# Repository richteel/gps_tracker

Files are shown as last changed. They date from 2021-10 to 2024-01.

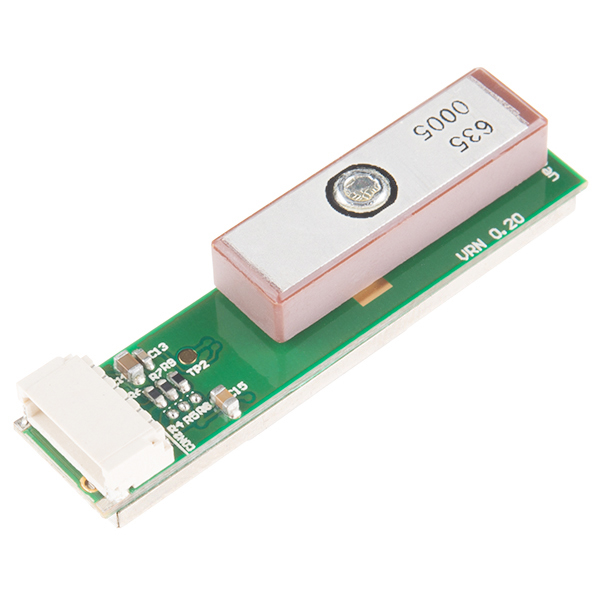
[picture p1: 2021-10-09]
docs/img/13670-01a.jpg

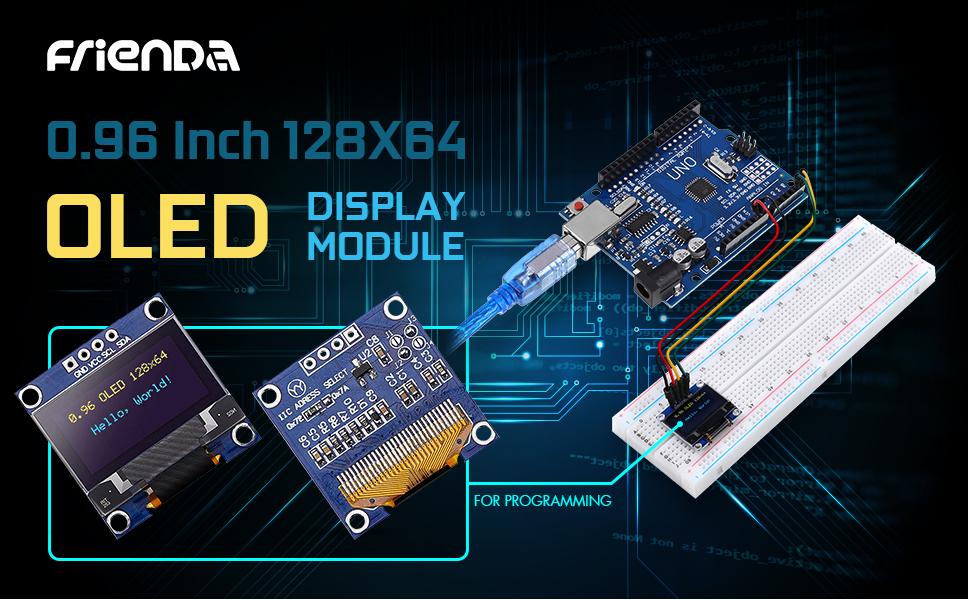
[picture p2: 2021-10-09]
docs/img/444afe57-f2d5-45a5-a1f3-c204e6212a6a.__CR0,0,970,600_PT0_SX970_V1___.jpg

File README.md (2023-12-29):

# gps_tracker
GPS Tracker and data logger

The files here include hardware, case, PCB, Python and C++ code, documentation, and reference files.

## Bill of Materials (BOM) ##
- Adafruit Feather RP2040
	- Qty: 1
	- Source: Adafruit [https://www.adafruit.com/product/4884](https://www.adafruit.com/product/4884 "Adafruit Feather RP2040")
- Adafruit Micro SD Breakout
	- Qty: 1
	- Source: Adafruit [https://www.adafruit.com/product/4682](https://www.adafruit.com/product/4682 "Adafruit Micro SD SPI or SDIO Card Breakout Board - 3V ONLY!")
- SPDT Slide Switch
	- Qty: 2
	- Source: Adafruit [https://www.adafruit.com/product/805](https://www.adafruit.com/product/805 "SPDT Slide Switch")
- Tactile Switch Push Button (6mm slim)
	- Qty: 4
	- Source: Adafruit [https://www.adafruit.com/product/1489](https://www.adafruit.com/product/1489 "Tactile Switch Push Button (6mm slim)")
- ST-PH 2-Pin SMT Right Angle Connector
	- Qty: 1
	- Source: Adafruit [https://www.adafruit.com/product/1769](https://www.adafruit.com/product/1769 "ST-PH 2-Pin SMT Right Angle Connector")
- GPS Receiver - GP-635T (50 Channel)
	- Qty: 1
	- Source: Sparkfun [https://www.sparkfun.com/products/retired/11571](https://www.sparkfun.com/products/retired/11571 "GPS Receiver - GP-635T (50 Channel)")
- JST SH Jumper 6 Wire Assembly - 8"
	- Qty: 1
	- Source: Sparkfun [https://www.sparkfun.com/products/10361](https://www.sparkfun.com/products/10361 "JST SH Jumper 6 Wire Assembly - 8 inch")
- I2C 128x64 OLED Display
	- Qty: 1
	- Source: Amazon [https://www.amazon.com/gp/product/B08VNRH5HR/ref=ppx_yo_dt_b_search_asin_title?ie=UTF8&th=1](https://www.amazon.com/gp/product/B08VNRH5HR/ref=ppx_yo_dt_b_search_asin_title?ie=UTF8&th=1 "I2C 128x64 OLED Display")
- 3.7V 680mAh 102530 Lipo Battery Rechargeable Lithium Polymer ion Battery Pack with JST Connector
	- Qty: 1
	- Source: Amazon [https://www.amazon.com/gp/product/B07BTPNS2B/ref=ppx_yo_dt_b_search_asin_title?ie=UTF8&psc=1](https://www.amazon.com/gp/product/B07BTPNS2B/ref=ppx_yo_dt_b_search_asin_title?ie=UTF8&psc=1 "3.7V 680mAh 102530 Lipo Battery Rechargeable Lithium Polymer ion Battery Pack with JST Connector")
	- **WARNING:** The battery from this source has reversed polarity. Change the pins to match correct orientation!
- CR2032 Coin Button Cell Battery Holder Case
	- Qty: 1
	- Source: Amazon [https://www.amazon.com/gp/product/B06XF3K4NP/ref=ppx_yo_dt_b_search_asin_image?ie=UTF8&psc=1](https://www.amazon.com/gp/product/B06XF3K4NP/ref=ppx_yo_dt_b_search_asin_image?ie=UTF8&psc=1 "CR2032 Coin Button Cell Battery Holder Case")
- CR2032 Battery
	- Qty: 1
	- Source: Battery Junction [https://www.batteryjunction.com/sony-cr2032-5pack](https://www.batteryjunction.com/sony-cr2032-5pack "CR2032 Battery")
- Resistor 4.7K Ω (0805 package)
	- Qty: 4
	- Source: DigiKey [https://www.digikey.com/en/products/filter/chip-resistor-surface-mount/52...](https://www.digikey.com/en/products/filter/chip-resistor-surface-mount/52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 ""Filter for Resistor 4.7K Ω (0805 package)")
- Resistor 2M Ω (0805 package)
	- Qty: 4
	- Source: DigiKey [https://www.digikey.com/en/products/filter/chip-resistor-surface-mount/52...](https://www.digikey.com/en/products/filter/chip-resistor-surface-mount/52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 ""Filter for Resistor 2M Ω (0805 package)") 
- Capacitor 0.1μF (0805 package)
	- Qty: 2
	- Source: DigiKey [https://www.digikey.com/en/products/filter/ceramic-capacitors/60...](https://www.digikey.com/en/products/filter/ceramic-capacitors/60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 "Filter for Capacitor 0.1μF (0805 package)")
- PCB
	- Qty: 1
	- Source: Shared on OSH Park [https://oshpark.com/shared_projects/GzuBZVdm](https://oshpark.com/shared_projects/GzuBZVdm "PCB")

# Log File #

The GPS Log Files are named with the format of YYYYMMDD.txt, where the letters are the following:

- YYYY: 4-digit Year
- MM: 2-digit Month
- DD: 2-digit Day

The data is comma separated, with the following columns.

- ISO 8601 formatted time-stamp (UTC) e.g. 2009-10-17T18:37:26Z
- Latitude in Degrees
- Longitude in Degrees
- Elevation in Meters
- Heading in Degrees
- Speed in Kpm

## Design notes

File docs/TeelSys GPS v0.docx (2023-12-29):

Original Screens

TeelSys GPS v0.4

12/23/2023 12:47:08

12/23/2023 07:46:12

Lat: 39.0131 N

Long: 77.3866 W

Alt: 128.1 m

Head:

Speed: 5.173 km/h

Sat: 9

Fix Q: 3 (3D)

Batt: 4.09 V

Batt: 88.33 %

Statu: Discharging

Card: Present

Size: 15.184 MB

Free: 15,170 MB

Files: 26

M Min: 126,224

DT 12/23/2023 12:50

GPS E: True

SD E: True

Loc T: 12:59:56

Loc L: 12:59:56

New Screens (12/23/2023)

TeelSys GPS v0.5 C++

Date TIME (GMT)

12/23/2023 12:47:08

Local (EST)

12/23/2023 07:46:12

Lat: 39.0131 N

Long: 77.3866 W

Alt: 128.10 m

Speed: 5.17 kph

Head: 38.97 deg

Satellites: 9

GPS Fix: Yes

Fix Quality: GPS

3D Quality: 3D

GPS Enabled: Yes

Battery: 4.09 V

Battery: 88.33 %

Status: Discharging

Card: Present

Size: 15.184 GB

Free: 15,170 GB

Files: 26

Memory:

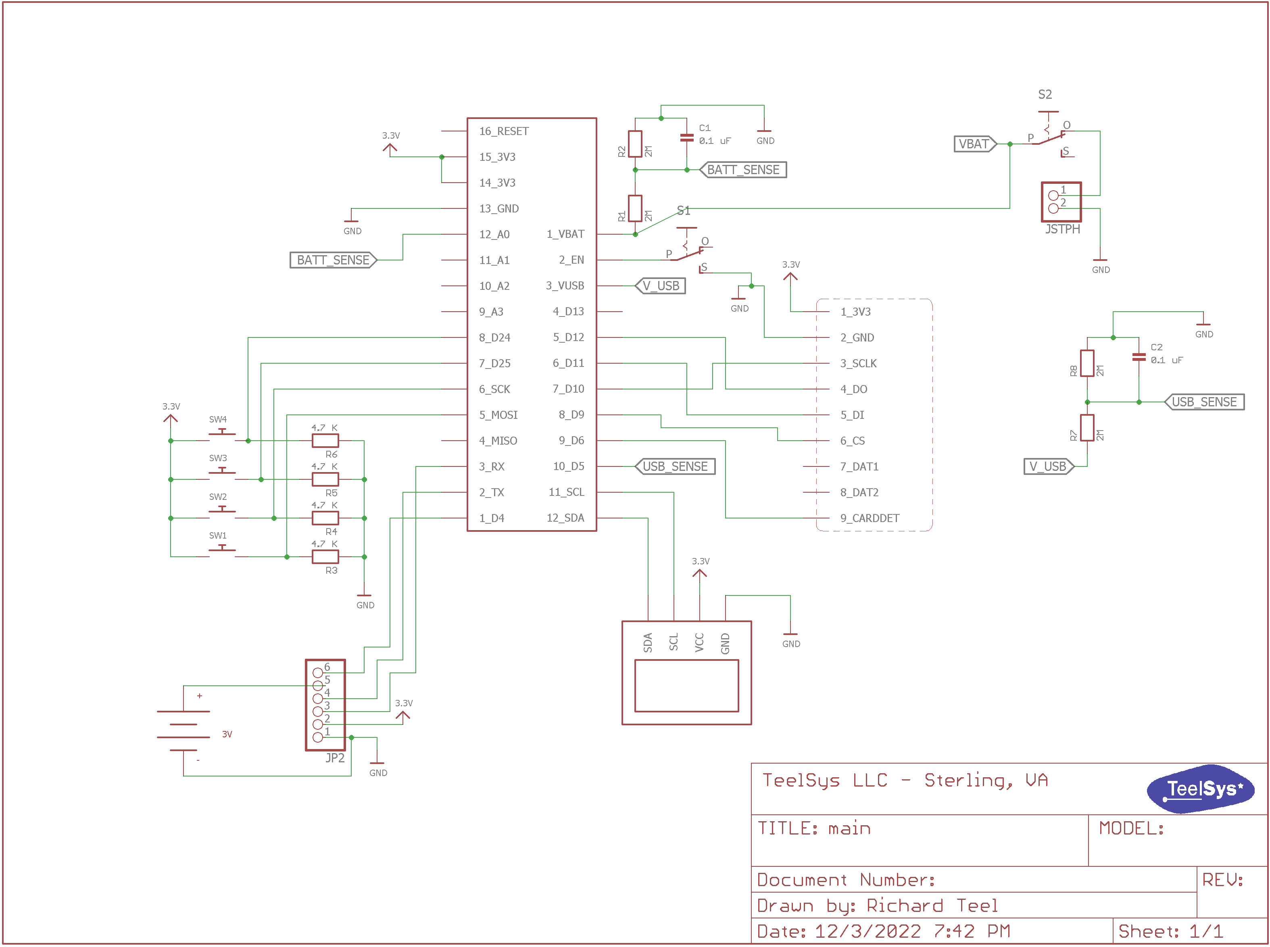
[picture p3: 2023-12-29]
docs/Schematic.png

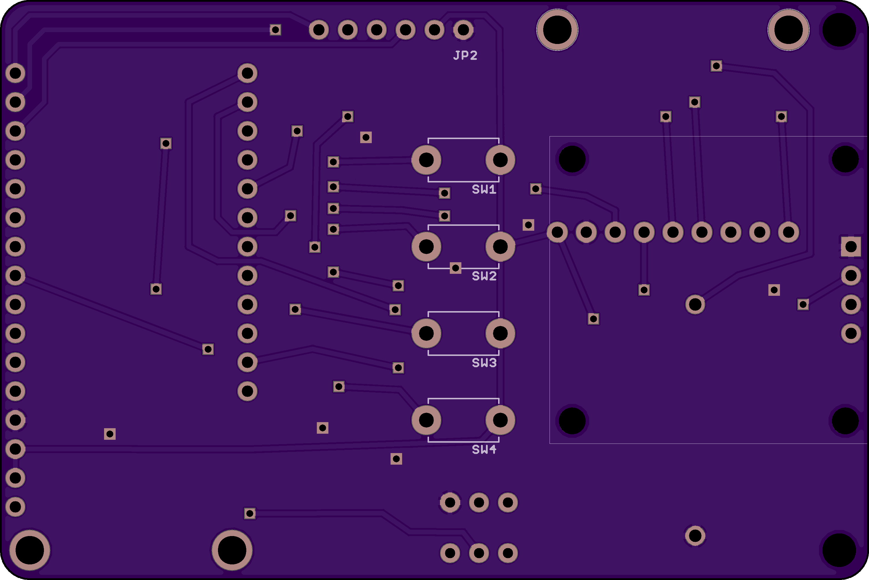
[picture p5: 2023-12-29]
docs/PCB_Top.png

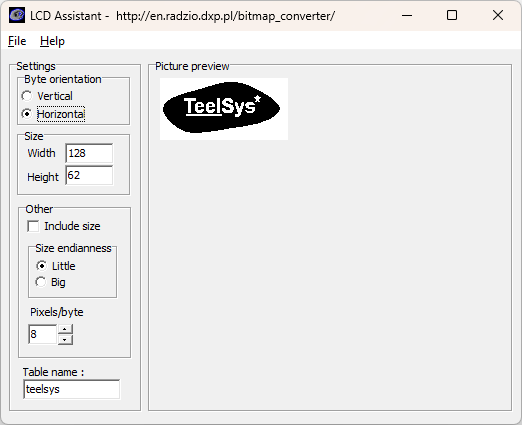
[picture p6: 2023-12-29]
docs/Screenshot_LCD_Assistant.png

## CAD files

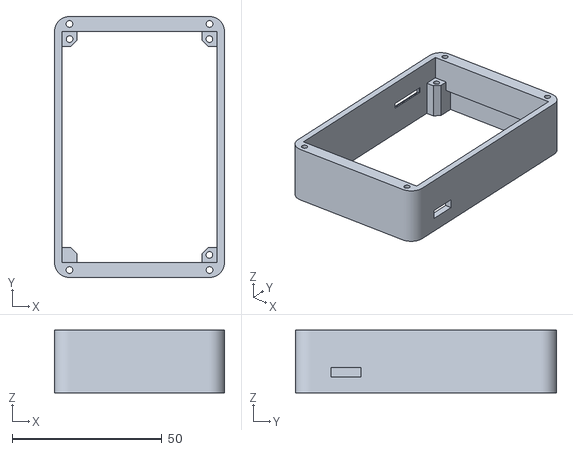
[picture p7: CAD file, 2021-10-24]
Case/GPS Case v2.stl
56.8 x 87.2 x 21.0

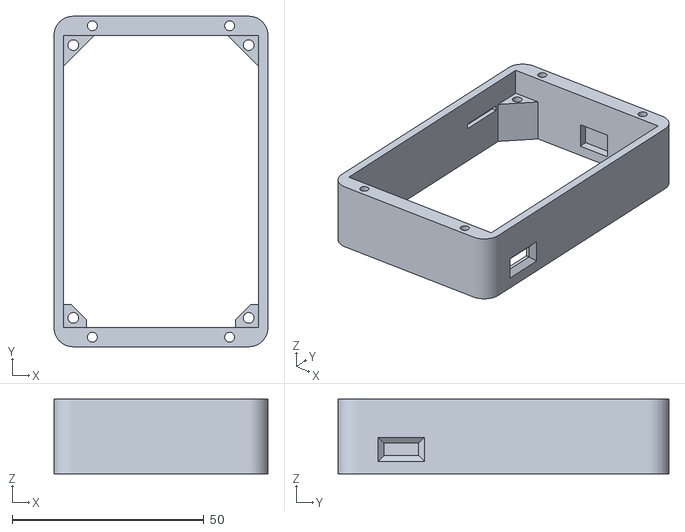
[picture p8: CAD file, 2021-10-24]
Case/v1/GPS Case.stl
55.8 x 86.2 x 19.4

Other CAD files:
Case/GPS Case v2.skp
Case/GPS Case.skp
Case/v1/GPS Case.skp

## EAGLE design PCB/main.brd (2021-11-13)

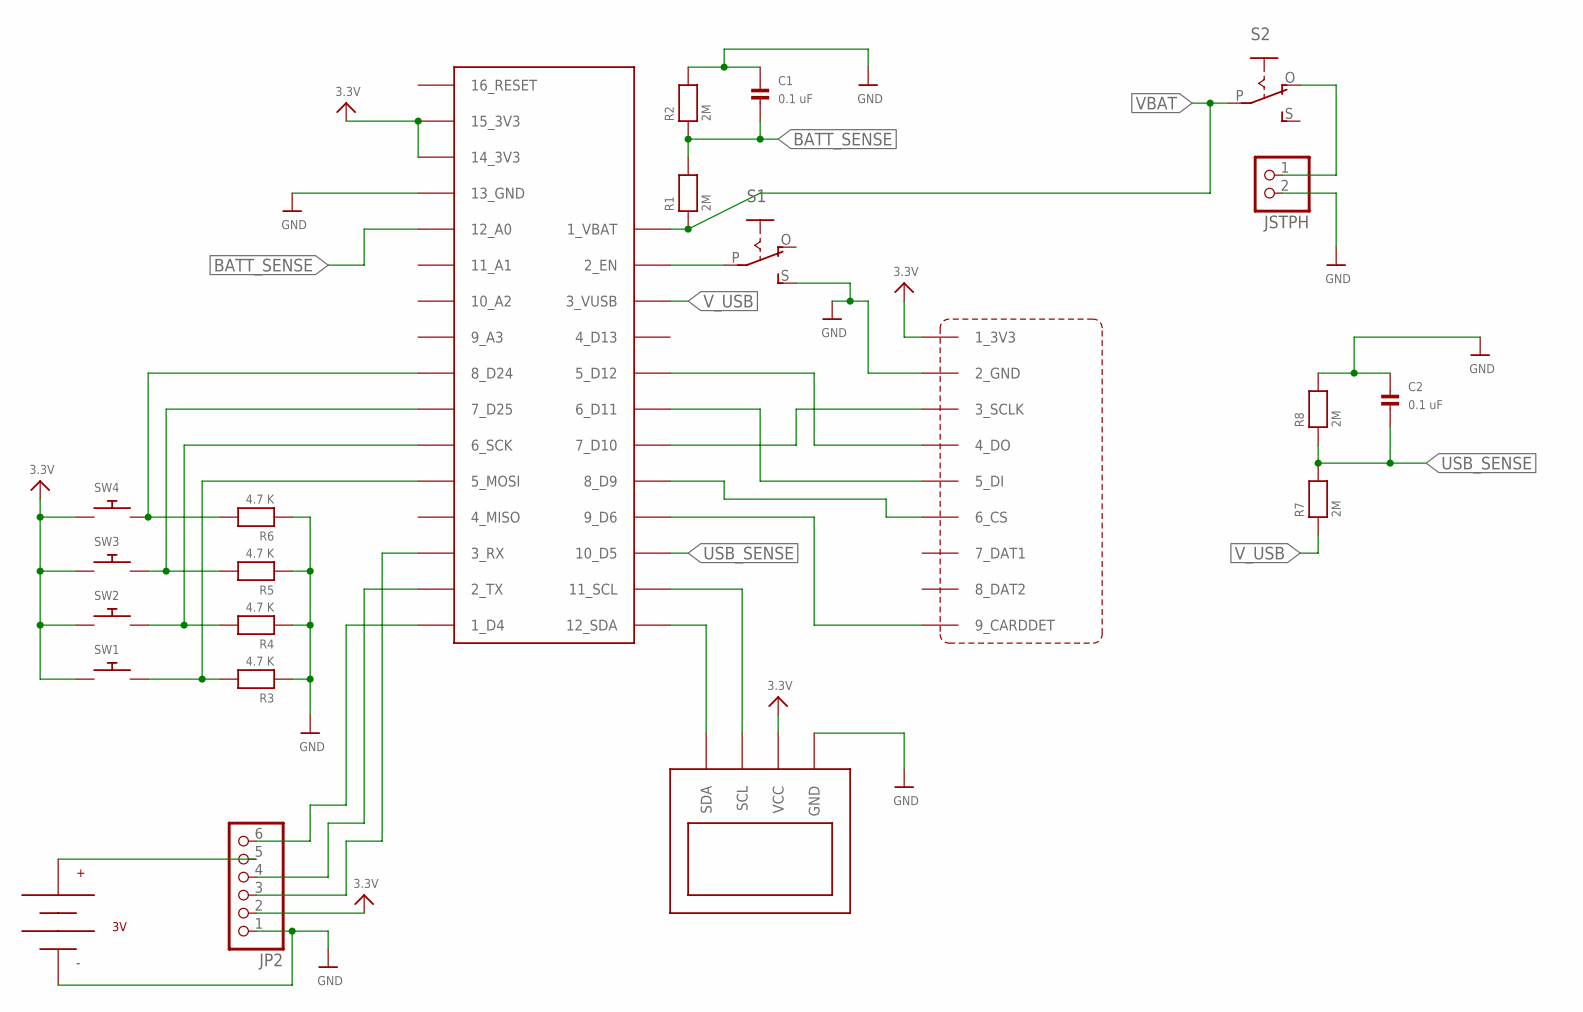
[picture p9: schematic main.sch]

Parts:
BAT_1: CR2032_HOLDER_WMYCONGCONG
C1, C2: 0.1 uF; _0805
FEATHER_RP2040: ADAFRUIT_FEATHER_RP2040; ADAFRUIT_FEATHER
JP2: HEADER-1X6ROUND; 1X06_ROUND
JSTPH: JST_2PIN-SMT-RA; JST-PH-2-SMT-RA
R1, R2, R7, R8: 2M; 0805
R3, R4, R5, R6: 4.7 K; 0805
S1, S2: EG1218S; EG1218
SDCARD2: ADAFRUIT_SDCARD3V3BOTTOM_MNT; ADAFRUIT_SDCARD3V3_B
SW1, SW2, SW3, SW4: SWITCH_PUSHBUTTONEVQ-PE; TACT_PANA-EVQ
U$10: OLED_SDD1306_128X64FRIENDA; OLED_SDD1306_128X64

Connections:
3.3V: FEATHER_RP2040.14_3V3, FEATHER_RP2040.15_3V3, JP2.2, SDCARD2.1_3V3, SW1.P$1, SW2.P$1, SW3.P$1, SW4.P$1, U$10.2_VCC (VCC)
BATT_SENSE: C1.2, FEATHER_RP2040.12_A0, R1.2, R2.1
GND: BAT_1.V- (-), C1.1, C2.1, FEATHER_RP2040.13_GND, JP2.1, JSTPH.2 (1), R2.2, R3.1, R4.1, R5.1, R6.1, R8.2, S1.S, SDCARD2.2_GND, U$10.1_GND (GND)
unnamed: FEATHER_RP2040.9_D6, SDCARD2.9_CARDDET
unnamed: FEATHER_RP2040.5_D12, SDCARD2.4_DO
unnamed: FEATHER_RP2040.7_D10, SDCARD2.3_SCLK
unnamed: FEATHER_RP2040.6_D11, SDCARD2.5_DI
unnamed: FEATHER_RP2040.8_D9, SDCARD2.6_CS
unnamed: FEATHER_RP2040.2_EN, S1.P
unnamed: FEATHER_RP2040.8_D24, R6.2, SW4.P$2
unnamed: FEATHER_RP2040.7_D25, R5.2, SW3.P$2
unnamed: FEATHER_RP2040.6_SCK, R4.2, SW2.P$2
unnamed: FEATHER_RP2040.5_MOSI, R3.2, SW1.P$2
unnamed: BAT_1.V+ (+), JP2.5
unnamed: FEATHER_RP2040.12_SDA, U$10.4_SDA (SDA)
unnamed: FEATHER_RP2040.11_SCL, U$10.3_SCL (SCL)
unnamed: JSTPH.1 (2), S2.O
unnamed: FEATHER_RP2040.3_RX, JP2.3
unnamed: FEATHER_RP2040.2_TX, JP2.4
unnamed: FEATHER_RP2040.1_D4, JP2.6
USB_SENSE: C2.2, FEATHER_RP2040.10_D5, R7.2, R8.1
VBAT: FEATHER_RP2040.1_VBAT, R1.1, S2.P
V_USB: FEATHER_RP2040.3_VBUS (3_VUSB), R7.1

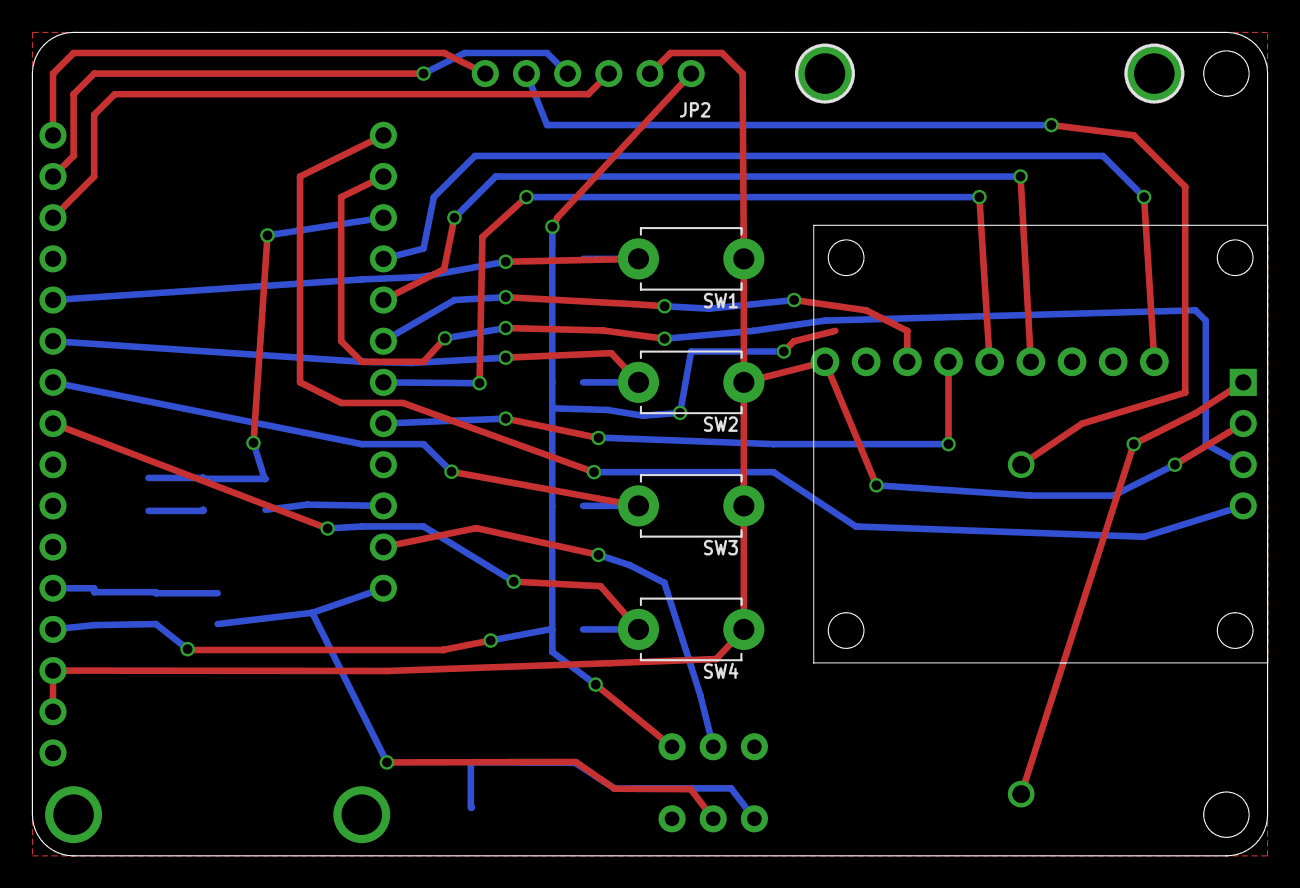
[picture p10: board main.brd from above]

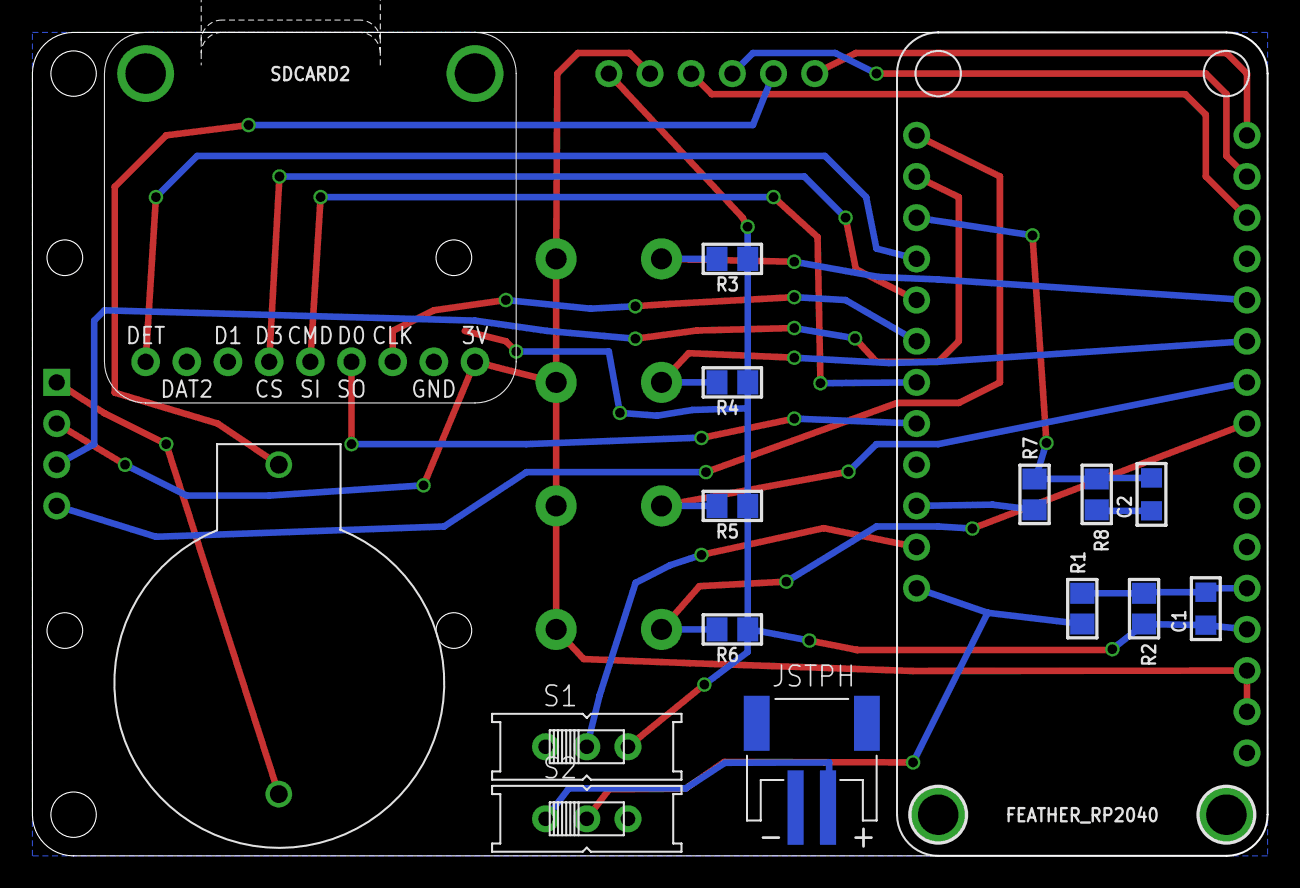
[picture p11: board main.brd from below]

Board: 2 copper layers, 76.2 x 50.8 mm, 22 parts (15 on the bottom side), 23 nets.

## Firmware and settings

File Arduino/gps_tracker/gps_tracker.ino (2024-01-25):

/*
          Hardware Pinouts
  --- Adafruit RP2040 Feather (4884) ---
  https://www.adafruit.com/product/4884
  https://cdn-learn.adafruit.com/assets/assets/000/107/203/original/adafruit_products_feather-rp2040-pins.png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

  Pin   C   Description
  -- GPS --
  D4    6   GPS PWR_CTRL (6) 0=Off/1=On
  TX    0   GPS RXA (4)
  RX    1   GPS TXA (3)
  -- Switches --
  MOSI  19  SW1   Left
  SCK   18  SW2   Left Middle
  D25   25  SW3   Right Middle
  D24   24  SW4   Right
  -- Battery Monitoring --
  A0    26  Battery Voltage
  D5    7   USB Detect
  -- OLED Display --
  SCL   3   OLED SCL
  SDA   2   OLED SDA
  -- SD Card --
  D6    8   SD Card Card Detect
  D9    0   SD Card CS
  D10   10  SD Card SCLK
  D11   11  SD Card DI
  D12   12  SD Card DO
  -- Feather --
  D13   13  LED
  D16   16  Neopixel  // Adafruit_NeoPixel pixels(NUMPIXELS, PIN, NEO_GRB + NEO_KHZ800);

  OLED Info
  -----------
  I2C Address: 0x3C
  Width: 128
  Height: 64

  GPS Info
  -----------
  BAUD: 9600
  TImeout: 10
*/

/*****************************************************************************
 *                                  DEFINES                                  *
 *****************************************************************************/
#define DEBUG 0
#define PRINTSCREENS 0
#define FILE_NAME "[SpeechTimer.ino]"

/*****************************************************************************
 *                              FreeRTOS Setup                               *
 *****************************************************************************/
#if !defined(ESP_PLATFORM) && !defined(ARDUINO_ARCH_MBED_RP2040) && !defined(ARDUINO_ARCH_RP2040)
#pragma message("Unsupported platform")
#endif

// ESP32:
#if defined(ESP_PLATFORM)
TaskHandle_t task_loop1;
void esploop1(void *pvParameters) {
  setup1();

  for (;;)
    loop1();
}
#endif

#if defined(ARDUINO_ARCH_MBED_RP2040) || defined(ARDUINO_ARCH_RP2040)
#include <FreeRTOS.h>
#include <task.h>
#include <semphr.h>
#define xPortGetCoreID get_core_num
#endif

/*****************************************************************************
 *                               Include Files                               *
 *****************************************************************************/
// #include <Dictionary.h>
#include <Adafruit_GPS.h>
#include <TimeLib.h>
#include <Adafruit_NeoPixel.h>

/*****************************************************************************
 *                               Project Files                               *
 *****************************************************************************/
#include "Defines.h"
#include "StructsAndEnums.h"
#include "screens.h"
#include "config.h"
#include "batteryClass.h"
#include "SD_Card.h"
#include "displayClass.h"

/*****************************************************************************
 *                                  DEFINES                                  *
 *****************************************************************************/
// What's the name of the hardware serial port connected to the GPS module?
#define GPSSerial Serial1
// Set GPSECHO to 'false' to turn off echoing the GPS data to the Serial console
// Set to 'true' if you want to debug and listen to the raw GPS sentences
// #define GPSECHO false

/*****************************************************************************
 *                                  GLOBALS                                  *
 *****************************************************************************/
// Flags to make certain that required initialization is complete before tasks start
bool setup_complete = false;
int waitLoopsToPrintTaskInfo = 100;

Switch switches[4];

// Module Objects
// Connect to the GPS on the hardware port
Adafruit_GPS GPS(&GPSSerial);
SD_Card sdCard = SD_Card();
batteryClass battery;
displayClass display;
Adafruit_NeoPixel pixels(1, PIN_FEATHER_NEO, NEO_GRB + NEO_KHZ800);

// GPS Log
time_t gps_last_logged_time;
int gps_log_interval = 10;

// Display
int currentScreenIndex = 0;

// Feather LED and Neopixel

/*****************************************************************************
 *                                 LOG FILES                                 *
 *****************************************************************************/
char logDebug[] = "/logs/debug.log";
char logDebugArchive[] = "/logs/debug_1.log";

/*****************************************************************************
 *                                   QUEUES                                  *
 *****************************************************************************/
static const uint8_t log_queue_len = 10;
static QueueHandle_t log_queue;

static const uint8_t switch_queue_len = 5;
static QueueHandle_t switch_queue;

static const uint8_t gps_queue_len = 5;
static QueueHandle_t gps_queue;

/*****************************************************************************
 *                                   MUTEX                                   *
 *****************************************************************************/
static SemaphoreHandle_t sdcard_mutex;
static SemaphoreHandle_t rtc_mutex;

/*****************************************************************************
 *                               INO FUNCTIONS                               *
 *****************************************************************************/
void debugMessage(const char *message) {
  return;
  // char timeStr[10];
  char msgBuffer[512];
  // clockRtc.getTimeString(timeStr);
  // Format the message
  snprintf(msgBuffer, sizeof(msgBuffer), "%s %s\t%d\t%d\t%d", "sketch_dec21a.ino", message, xPortGetCoreID(), rp2040.getFreeHeap(), uxTaskGetStackHighWaterMark(NULL));

  Serial.println(msgBuffer);
}

void gpsWriteToLog(GpsInfo gpsData) {
  /*
  ISO Time format
    https://en.wikipedia.org/wiki/GPS_Exchange_Format
    2009-10-17T18:37:26Z
    strftime
    %Y-%m-%dT%TZ
    size_t strftime (char* ptr, size_t maxsize, const char* format,                 const struct tm* timeptr );
  */

  // 2023-12-28T02:02:48Z,39.012863,-77.386467,100.199997,288.170013,0.490000
  // 2023-12-28T02:02:04Z,39.012882,-77.386467,100.900002,288.170013,0.439000
  if (sdCard.cardPresent && gpsData.fix && gpsData.epoch - gps_last_logged_time >= gps_log_interval) {
    gps_last_logged_time = gpsData.epoch;

    char filename[80];
    char logBuffer[80];
    snprintf(filename, sizeof(filename), "/gpsdata/%04d%02d%02d.txt", year(gpsData.epoch), gpsData.month, gpsData.day);
    snprintf(logBuffer, sizeof(logBuffer), "%s,%s,%f,%f,%f,%f,%f", gpsData.utc_date, gpsData.utc_time, gpsData.latitudeDegrees, gpsData.longitudeDegrees, gpsData.altitude, gpsData.angle, (gpsData.speed * 1000.852));

    if (xSemaphoreTake(sdcard_mutex, 10) == pdTRUE) {
      // Write file header if file does not exist already
      if (!sdCard.fileExists(filename)) {
        sdCard.writeLogEntry(filename, "utc_d,utc_t,lat,lon,alt,head,speed");
      }
      sdCard.writeLogEntry(filename, logBuffer);
      xSemaphoreGive(sdcard_mutex);
    } else {
      Serial.printf("%s: %s gpsWriteToLog - Failed to write gps entry to the SD Card. (Could not obtain mutex.)\n", debugLevelName[DebugLevels::Error], FILE_NAME);
    }
    // Serial.printf("%s\t%s\n", filename, logBuffer);
  }
}

void ledOnOff(bool turnOn) {
  digitalWrite(PIN_FEATHER_LED, turnOn);
}

void ledToggle() {
  digitalWrite(PIN_FEATHER_LED, !digitalRead(PIN_FEATHER_LED));
}

void neopixelToggle(bool toggleRed, bool toggleBlue, bool toggleGreen) {
  uint32_t c = pixels.getPixelColor(0);
  uint32_t maskToggle = pixels.Color(toggleRed ? 255 : 0, toggleBlue ? 255 : 0, toggleGreen ? 255 : 0);
  uint32_t maskKeep = ~maskToggle;
  uint32_t valueToggle = c & maskToggle;
  uint32_t valueKeep = c & maskKeep;

  if (valueToggle == 0) {
    valueToggle = maskToggle;
  } else {
    valueToggle = 0;
  }

  uint32_t valueNew = valueKeep | valueToggle;

  pixels.setPixelColor(0, valueNew);
  pixels.show();
}

int lastSec = 0;
int secRepeat = 0;

void printScreens() {
  if (!PRINTSCREENS) {
    return;
  }

  int secNow = second(now());
  if (secNow != lastSec) {
    lastSec = secNow;
    secRepeat = 1;
  } else {
    secRepeat++;
  }

  for (int i = 0; i < secRepeat; i++) {
    Serial.print(".");
  }
  Serial.println();


  for (int i = 0; i < NUM_OF_SCREENS; i++) {
    Serial.printf("----- SCREEN %d -----\n", i + 1);
    Serial.println(screens[i].line1);
    Serial.println(screens[i].line2);
    Serial.println(screens[i].line3);
    Serial.println(screens[i].line4);
    Serial.println(screens[i].line5);
  }
}

void updateScreenCardInfo() {
  sdCard.updateCardInfo();
  snprintf(screens[4].line1, 22, " Card: %s", sdCard.cardInfo.cardInserted ? "Present" : "Missing");
  snprintf(screens[4].line2, 22, " Type: %s", sdCard.cardInfo.cardType);
  snprintf(screens[4].line3, 22, "Total: %s", sdCard.cardInfo.totalSize);
  snprintf(screens[4].line4, 22, " Free: %s", sdCard.cardInfo.freeSize);
  snprintf(screens[4].line5, 22, "Files: %8d", sdCard.cardInfo.fileCount);
}

void updateScreenDateTime() {
  time_t time_gmt = now();
  time_t time_local = time_gmt + (sdCard.sdCardConfig.gmtOffset * SECS_PER_HOUR);

  snprintf(screens[0].line2, 22, "   Date Time (UTC)");
  snprintf(screens[0].line3, 22, "%02d/%02d/%d %02d:%02d:%02d", month(time_gmt), day(time_gmt), year(time_gmt), hour(time_gmt), minute(time_gmt), second(time_gmt));
  snprintf(screens[0].line4, 22, "     Local (%s)", sdCard.sdCardConfig.tzAbbr);
  snprintf(screens[0].line5, 22, "%02d/%02d/%d %02d:%02d:%02d", month(time_local), day(time_local), year(time_local), hour(time_local), minute(time_local), second(time_local));
}

void updateScreenMemoryInfo() {
  int total = rp2040.getTotalHeap();
  int free = rp2040.getFreeHeap();
  float percentFree = ((float)free / (float)total) * 100.0f;
  float freq = ((float)rp2040.f_cpu()) / 1000000.0f;
  snprintf(screens[5].line1, 22, "    MEMORY: Heap");
  snprintf(screens[5].line2, 22, "Total: %6d b", total);
  snprintf(screens[5].line3, 22, " Free: %6d b", free);
  snprintf(screens[5].line4, 22, "       %6.2f %%", percentFree);
  snprintf(screens[5].line5, 22, " Freq: %6.2f MHz", freq);
}

/*****************************************************************************
 *                                   TASKS                                   *
 *****************************************************************************/
void checkBattery(void *param) {
  // Make certain that setup has completed
  while (!setup_complete) {
    vTaskDelay(10 / portTICK_PERIOD_MS);
  }

  int loopCount = 0;

  while (1) {
    battery.updateBattery();

    snprintf(screens[3].line1, 22, "Battery: %6.2f V", battery.batteryVoltage);
    snprintf(screens[3].line2, 22, "Battery: %6.2f %%", battery.batteryPercent);
    snprintf(screens[3].line3, 22, " Status: %s", batteryChargeStateName[battery.batteryChargeState]);

    loopCount++;
    // Print message with stack usage once every ten loops
    if (loopCount > waitLoopsToPrintTaskInfo) {
      debugMessage("checkBattery");
      loopCount = 0;
    }
    vTaskDelay(500 / portTICK_PERIOD_MS);
  }  // End Loop
}

void checkGps(void *param) {
  // Make certain that setup has completed
  while (!setup_complete) {
    vTaskDelay(10 / portTICK_PERIOD_MS);
  }

  int loopCount = 0;

  uint32_t timer = millis();

  pinMode(PIN_GPS_CTRL, OUTPUT);
  digitalWrite(PIN_GPS_CTRL, HIGH);

  // 9600 NMEA is the default baud rate for Adafruit MTK GPS's- some use 4800
  GPS.begin(9600);
  // uncomment this line to turn on RMC (recommended minimum) and GGA (fix data) including altitude
  GPS.sendCommand(PMTK_SET_NMEA_OUTPUT_RMCGGA);
  // uncomment this line to turn on only the "minimum recommended" data
  //GPS.sendCommand(PMTK_SET_NMEA_OUTPUT_RMCONLY);
  // For parsing data, we don't suggest using anything but either RMC only or RMC+GGA since
  // the parser doesn't care about other sentences at this time
  // Set the update rate
  GPS.sendCommand(PMTK_SET_NMEA_UPDATE_1HZ);  // 1 Hz update rate
  // For the parsing code to work nicely and have time to sort thru the data, and
  // print it out we don't suggest using anything higher than 1 Hz
  // Request updates on antenna status, comment out to keep quiet
  GPS.sendCommand(PGCMD_ANTENNA);

  vTaskDelay(1000 / portTICK_PERIOD_MS);

  // Ask for firmware version
  GPSSerial.println(PMTK_Q_RELEASE);

  while (1) {
    // DELETE NEXT 3 LINES!!!
    // read data from the GPS in the 'main loop'
    char c = GPS.read();
    // Serial.printf("GPS Data: %c\n", c);

    GpsInfo gpsInfo;
    // if a sentence is received, we can check the checksum, parse it...
    if (GPS.newNMEAreceived()) {
      // a tricky thing here is if we print the NMEA sentence, or data
      // we end up not listening and catching other sentences!
      // so be very wary if using OUTPUT_ALLDATA and trying to print out data
      // Commented this line to stop dumping raw data // Serial.print(GPS.lastNMEA()); // this also sets the newNMEAreceived() flag to false
      if (GPS.parse(GPS.lastNMEA())) {  // this also sets the newNMEAreceived() flag to false
        loopCount++;
        continue;
      }
    }

    // approximately every 2 seconds or so, print out the current stats
    if (millis() - timer > 2010) {
      timer = millis();  // reset the timer
      // gpsInfo.epoch = { 2000 + GPS.year, GPS.month, GPS.day, GPS.hour, GPS.minute, GPS.seconds, GPS.milliseconds };
      // rtc_set_datetime(&gpsInfo.epoch);
      tmElements_t myElements = { GPS.seconds, GPS.minute, GPS.hour, 0, GPS.day, GPS.month, (uint8_t)(GPS.year + 30) };
      gpsInfo.epoch = makeTime(myElements);
      if (timeStatus() != timeSet || gpsInfo.epoch != now()) {
        // setTime(GPS.hour, GPS.minute, GPS.seconds, GPS.day, GPS.month, GPS.year);
        setTime(gpsInfo.epoch);
        Serial.println("\n\n*** Time Set***\n");
        ledOnOff(true);
      }
      gpsInfo.hour = GPS.hour;
      gpsInfo.minute = GPS.minute;
      gpsInfo.seconds = GPS.seconds;
      gpsInfo.year = GPS.year;
      gpsInfo.month = GPS.month;
      gpsInfo.day = GPS.day;
      gpsInfo.latitudeDegrees = GPS.latitudeDegrees;
      gpsInfo.longitudeDegrees = GPS.longitudeDegrees;
      gpsInfo.altitude = GPS.altitude;
      gpsInfo.speed = GPS.speed;
      gpsInfo.angle = GPS.angle;
      gpsInfo.fixquality = (GPS_FIX_QUALITY)GPS.fixquality;
      gpsInfo.fixquality_3d = (GPS_FIX_QUALITY_3D)GPS.fixquality_3d;
      gpsInfo.satellites = GPS.satellites;
      gpsInfo.fix = GPS.fix;
      strftime(gpsInfo.isoTime, sizeof(gpsInfo.isoTime), "%Y-%m-%dT%TZ", gmtime(&gpsInfo.epoch));
      strftime(gpsInfo.utc_date, sizeof(gpsInfo.utc_date), "%Y-%m-%d", gmtime(&gpsInfo.epoch));
      strftime(gpsInfo.utc_time, sizeof(gpsInfo.utc_date), "%T", gmtime(&gpsInfo.epoch));

      if (xQueueSend(gps_queue, (void *)&gpsInfo, 10) != pdTRUE) {
        Serial.println(F("checkGps - GPS Queue Full -----------------------------"));
      }
    }

    loopCount++;
    // Print message with stack usage once every ten loops
    if (loopCount > waitLoopsToPrintTaskInfo) {
      debugMessage("checkGps");
      loopCount = 0;
      ledOnOff(false);
    }
    // vTaskDelay(2000 / portTICK_PERIOD_MS);
  }  // End Loop
}

void checkSdCard(void *param) {
  // Make certain that setup has completed
  while (!setup_complete) {
    vTaskDelay(10 / portTICK_PERIOD_MS);
  }

  int loopCount = 0;
  Log_Entry item;

  // Force initial loading of config file
  sdCard.cardPresent = false;

  while (1) {
    // Handle if the card was removed and/or reinserted
    sdCard.isCardPresent();

    // Check if there are log entries to write to the SD Card
    bool writeToFile = false;
    while (xQueueReceive(log_queue, (void *)&item, 0) == pdTRUE) {
      if (sdCard.cardPresent && strlen(item.logfile) > 0) {
        writeToFile = true;
      }

      if (writeToFile) {
        if (xSemaphoreTake(sdcard_mutex, 10) == pdTRUE) {
          sdCard.writeLogEntry(item.logfile, item.message);
          xSemaphoreGive(sdcard_mutex);
        } else {
          Serial.printf("%s: %s checkSdCard - Failed to write log entry to the SD Card. (Could not obtain mutex.)\n", debugLevelName[DebugLevels::Error], FILE_NAME);
          writeToFile = false;
        }
      } else {
        // DEBUGV("%s\n", item.message);
        Serial.printf("%s\n", item.message);
      }
    }

    loopCount++;
    // Print message with stack usage once every ten loops
    if (loopCount > waitLoopsToPrintTaskInfo) {
      debugMessage("checkSdCard");
      loopCount = 0;
    }
    vTaskDelay(250 / portTICK_PERIOD_MS);
  }
}

void checkSwitches(void *param) {
  // Make certain that setup has completed
  while (!setup_complete) {
    vTaskDelay(10 / portTICK_PERIOD_MS);
  }

  int loopCount = 0;

  unsigned long lastDebounceTime = 0;  // the last time the output pin was toggled
  unsigned long debounceDelay = 35;    // the debounce time; increase if the output flickers

  uint32_t displayOnTimer = millis();

  switches[0].pin = PIN_SW0;
  switches[1].pin = PIN_SW1;
  switches[2].pin = PIN_SW2;
  switches[3].pin = PIN_SW3;

  // Setup Switches
  for (int i = 0; i < 4; i++) {
    switches[i].index = i;
    pinMode(switches[i].pin, INPUT);
  }

  while (1) {
    bool statechanged = false;
    // read the state of the switches into a local variable:
    for (int i = 0; i < 4; i++) {
      switches[i].current = digitalRead(switches[i].pin);
      if (switches[i].current != switches[i].last) {
        statechanged = true;
      }
    }

    // If the switch changed, due to noise or pressing:
    if (statechanged) {
      // wait for things to calm down
      vTaskDelay(debounceDelay / portTICK_PERIOD_MS);

      displayOnTimer = millis();
    } else {
      if (display.displayOn && (millis() - displayOnTimer) > (sdCard.sdCardConfig.displayOffSecs * 1000)) {
        display.toggleDisplayOnOff(false, true);
      }
    }

    for (int i = 0; i < 4; i++) {
      SwitchStates lastState = switches[i].state;

      if (switches[i].current && !switches[i].last) {
        switches[i].state = SwitchStates::Pressed;
      } else if (!switches[i].current && switches[i].last) {
        switches[i].state = SwitchStates::Released;
      } else if (switches[i].current == 1) {
        switches[i].state = SwitchStates::Down;
      } else {
        switches[i].state = SwitchStates::Up;
      }

      switches[i].last = switches[i].current;

      if (switches[i].state != lastState) {
        if (xQueueSend(switch_queue, (void *)&switches[i], 10) != pdTRUE) {
          Serial.println(F("checkSwitches - Switch Queue Full -----------------------------"));
        }
      }
    }

    loopCount++;
    // Print message with stack usage once every ten loops
    if (loopCount > waitLoopsToPrintTaskInfo) {
      debugMessage("checkSwitches");
      loopCount = 0;
    }
    vTaskDelay(debounceDelay / portTICK_PERIOD_MS);
  }  // End Loop
}

void handleSwitches(void *param) {
  // Make certain that setup has completed
  while (!setup_complete) {
    vTaskDelay(10 / portTICK_PERIOD_MS);
  }

  int loopCount = 0;

  Switch item;

  while (1) {

    while (xQueueReceive(switch_queue, (void *)&item, 0) == pdTRUE) {
      // Serial.printf("SW%d %s\n", item.index, switchStateName[item.state]);
      if (item.state == SwitchStates::Pressed) {
        if (!display.displayOn) {
          display.toggleDisplayOnOff(true, false);
          pixels.setPixelColor(0, 0);
          pixels.show();
        } else {
          switch (item.index) {
            case 0:
              // display.toggleDisplayOnOff();
              // pixels.setPixelColor(0, 0);
              // pixels.show();
              break;
            case 1:
              if (display.displayOn) {
                currentScreenIndex--;
                if (currentScreenIndex < 0) {
                  currentScreenIndex = NUM_OF_SCREENS - 1;
                }
              } else {
                neopixelToggle(1, 0, 0);
              }
              break;
            case 2:
              if (display.displayOn) {
                currentScreenIndex++;
                if (currentScreenIndex >= NUM_OF_SCREENS) {
                  currentScreenIndex = 0;
                }
              } else {
                neopixelToggle(0, 1, 0);
              }
              break;
            case 3:
              if (display.displayOn) {
                sdCard.sdCardConfig.metric = !sdCard.sdCardConfig.metric;
              } else {
                neopixelToggle(0, 0, 1);
              }
              break;
            default:
              break;
          }
        }
      }
      Serial.printf("Switch %d %s\n", item.index, switchStateName[item.state]);
      if (item.state == SwitchStates::Up) {
        Serial.println();
      }
    }

    loopCount++;
    // Print message with stack usage once every ten loops
    if (loopCount > waitLoopsToPrintTaskInfo) {
      debugMessage("handleSwitches");
      loopCount = 0;
    }
    vTaskDelay(150 / portTICK_PERIOD_MS);
  }  // End Loop
}
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
void loop() {
  // put your main code here, to run repeatedly:
}

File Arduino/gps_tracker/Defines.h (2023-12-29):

#ifndef DEFINES_H
#define DEFINES_H

// ***** Pins *****
#define NO_PIN 255

//-- GPS --
#define PIN_GPS_CTRL 6
#define PIN_GPS_TX 0
#define PIN_GPS_RX 1
//-- Switches --
#define PIN_SW0 19
#define PIN_SW1 18
#define PIN_SW2 25
#define PIN_SW3 24
//-- Battery Monitoring --
#define PIN_BAT_V A0
#define PIN_USB_D 7
//-- OLED Display --
#define PIN_OLED_SCL 3
#define PIN_OLED_SDA 2
//-- SD Card --
#define PIN_SD_CD 8
#define PIN_SD_CS 9
#define PIN_SD_SCLK 10
#define PIN_SD_DI 11  // MOSI
#define PIN_SD_DO 12  // MISO
//-- Feather --
#define PIN_FEATHER_LED 13
#define PIN_FEATHER_NEO 16

// Screen
#define SCREEN_WIDTH 128
#define SCREEN_HEIGHT 64
#define OLED_RESET -1        // Reset pin # (or -1 if sharing Arduino reset pin)
#define SCREEN_ADDRESS 0x3C  ///< See datasheet for Address; 0x3D for 128x64, 0x3C for 128x32

#endif  // DEFINES_H

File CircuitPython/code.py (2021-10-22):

import time

import helper

import hw_battery
import hw_display
import hw_gps
import hw_rtc
import hw_sdcard
import hw_switches

import dispItems
import log_battery
import log_gps

import gc

timers = {
    "batteryUpdate" : {"last_update": time.monotonic(), "updateInterval": 1},
    "displayUpdate" : {"last_update": time.monotonic(), "updateInterval": 1},
    "rtcUpdate" : {"last_update": time.monotonic(), "updateInterval": 1},
    "sdCardUpdate" : {"last_update": time.monotonic(), "updateInterval": 1},
    "timeSync" : {"last_update": time.monotonic(), "updateInterval": 300},
    "test" : {"last_update": time.monotonic(), "updateInterval": 10},
    "batteryLog" : {"last_update": time.monotonic(), "updateInterval": 5},
    "gpsLog" : {"last_update": time.monotonic(), "updateInterval": 1}
}

debug = False

def pollButtons():
    b = 0
    while b < hw_switches.getSwitchCount():
        if hw_switches.getSwitchState(b):
            print("Button {} pressed".format(b + 1))
            # write code here to handle button presses
            if b == 0:
                hw_display.toggleEnable()
            elif b == 1:
                hw_display.changeScreen(-1)
            elif b == 2:
                hw_display.changeScreen(1)
            elif b == 3:
                hw_sdcard.toggleEnable()
                hw_gps.toggleEnable()

        b += 1

hw_battery.begin()
hw_gps.begin()
hw_sdcard.begin()
hw_rtc.begin()
hw_display.begin()
hw_switches.begin()

minFreeMemory = gc.mem_free()

while True:
    hw_gps.update()

    # HANDLE SWITCHES
    pollButtons()

    memFree = gc.mem_free()
    if memFree < minFreeMemory:
        minFreeMemory = memFree
        dispItems.info["minMemory"]["value"] = \
            helper.dataToString(minFreeMemory, "{:,}")
        dispItems.info["minMemoryDT"]["value"] = \
            helper.datetimeDisplay(helper.the_rtc, False)

    current = time.monotonic()

    # SYNC RTC
    if current - timers["timeSync"]["last_update"] >= \
            timers["timeSync"]["updateInterval"] or \
            not helper.timeValid(helper.the_rtc):
        timers["timeSync"]["last_update"] = current

        # if helper.gps.has_fix:
        if helper.gps.datetime:
            # Set the RTC
            hw_rtc.syncClock(helper.gps)
            print("")
            print("****************************")
            print("* RTC Time Sync'd with GPS *")
            print("****************************")

    # UPDATE RTC
    if current - timers["rtcUpdate"]["last_update"] >= \
            timers["rtcUpdate"]["updateInterval"]:
        timers["rtcUpdate"]["last_update"] = current

        hw_rtc.update()
        pollButtons()

    # UPDATE BATTERY
    if current - timers["batteryUpdate"]["last_update"] >= \
            timers["batteryUpdate"]["updateInterval"]:
        timers["batteryUpdate"]["last_update"] = current

        hw_battery.update()
        pollButtons()

    # UPDATE SD CARD
    if current - timers["sdCardUpdate"]["last_update"] >= \
            timers["sdCardUpdate"]["updateInterval"]:
        timers["sdCardUpdate"]["last_update"] = current

        hw_sdcard.update()
        pollButtons()

    # UPDATE DISPLAY
    if current - timers["displayUpdate"]["last_update"] >= \
            timers["displayUpdate"]["updateInterval"]:
        timers["displayUpdate"]["last_update"] = current

        hw_display.update()
        pollButtons()

    # LOG BATTERY
    if current - timers["batteryLog"]["last_update"] >= \
            timers["batteryLog"]["updateInterval"] \
            and helper.timeValid(helper.the_rtc):
        timers["batteryLog"]["last_update"] = current

        log_battery.log()
        pollButtons()

    # LOG GPS
    if current - timers["gpsLog"]["last_update"] >= \
            timers["gpsLog"]["updateInterval"] \
            and helper.timeValid(helper.the_rtc):
        timers["gpsLog"]["last_update"] = current

        log_gps.log()
        pollButtons()

    # Test
    if current - timers["test"]["last_update"] >= \
            timers["test"]["updateInterval"]:
        timers["test"]["last_update"] = current

        if debug:
            print("********** DISPLAY **********")
            for item in hw_display.items:
                print("{} {}".format(item["label"], item["value"]))

            print("********** LOG BATTERY **********")
            for item in log_battery.items:
                print("{} {}".format(item["label"], item["value"]))

            print("********** LOG GPS **********")
            for item in log_gps.items:
                print("{} {}".format(item["label"], item["value"]))

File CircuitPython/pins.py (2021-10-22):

import board

# Battery
battVoltage = board.A0
usbDetect = board.D5

# Display
displayWidth = 128
displayHeight = 64
displayScl = board.SCL
displaySda = board.SDA
displayI2cAddress = 0x3C

# GPS
gpsTX = board.TX
gpsRX = board.RX
gpsBaud = 9600
gpsTimeOut = 10
gpsEnable = board.D4

# SD Card
sdCardCD = board.D6
sdCardCS = board.D9
sdCardSCK = board.D10
sdCardMOSI = board.D11
sdCardMISO = board.D12
sdCardLED = board.LED

# Switches
switchPins = [board.MOSI, board.SCK, board.D25, board.D24]

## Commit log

2021-10-09 Updated CircuitPython code and added PCB Design (sent to OSH Park)
2021-10-22 Appears to be the most stable code thus far with very responsive button and SD Card handling. May have issues with the log files with the date missing sometimes.
    [Battery Data2 - Copy.xlsx, Battery Data2.xlsx]
2021-10-24 Fixed an issue with log file format No tab delimiters due to forgetting to increment the column count
    [log_battery.py, log_gps.py]
2021-10-24 Files for the case
    [GPS Case v2.skp, GPS Case v2.stl, GPS Case.skp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]
2021-10-27 Fixed small issue with battery icon and adjusted min and max voltages
    [helper.py, hw_battery.py, hw_display.py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]
2021-11-13 Updates to front and back covers
    [Battery Data3.xlsx]
2021-11-13 Updated Case
2021-11-13 Updated PCB
    [main.brd, main.sch]
2023-12-29 Updating Arduino C++ Version and documentation
    [TeelSys GPS v0.4 .xlsx, config.txt]
2024-01-06 Fixed an issue with the GPS Log file name. Day was not formatted properly, so there was a space for one digit days. The format should have been day padded with a zero.
    202401 6.txt should have been 20240106.txt
    [gps_tracker.ino]

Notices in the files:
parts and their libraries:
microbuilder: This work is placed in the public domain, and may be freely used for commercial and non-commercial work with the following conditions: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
